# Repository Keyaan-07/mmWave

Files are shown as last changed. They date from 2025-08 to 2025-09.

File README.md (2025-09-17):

# mmWave Radar
This project includes building a complete mmWave radar that could operate at 60GHz. It uses the Texas Instruments IWRL6432 as the radar IC. This radar IC is operable between 57GHz-64GHz. The main goal of this project is to make a small module to use this IC as a radar. 
The board is a 6 layer board(4 layer was possible but 6 layers was cheaper). The 6 layer board costs only $2. 

[KICANVAS](https://kicanvas.org?)

# Images
Schematic:  
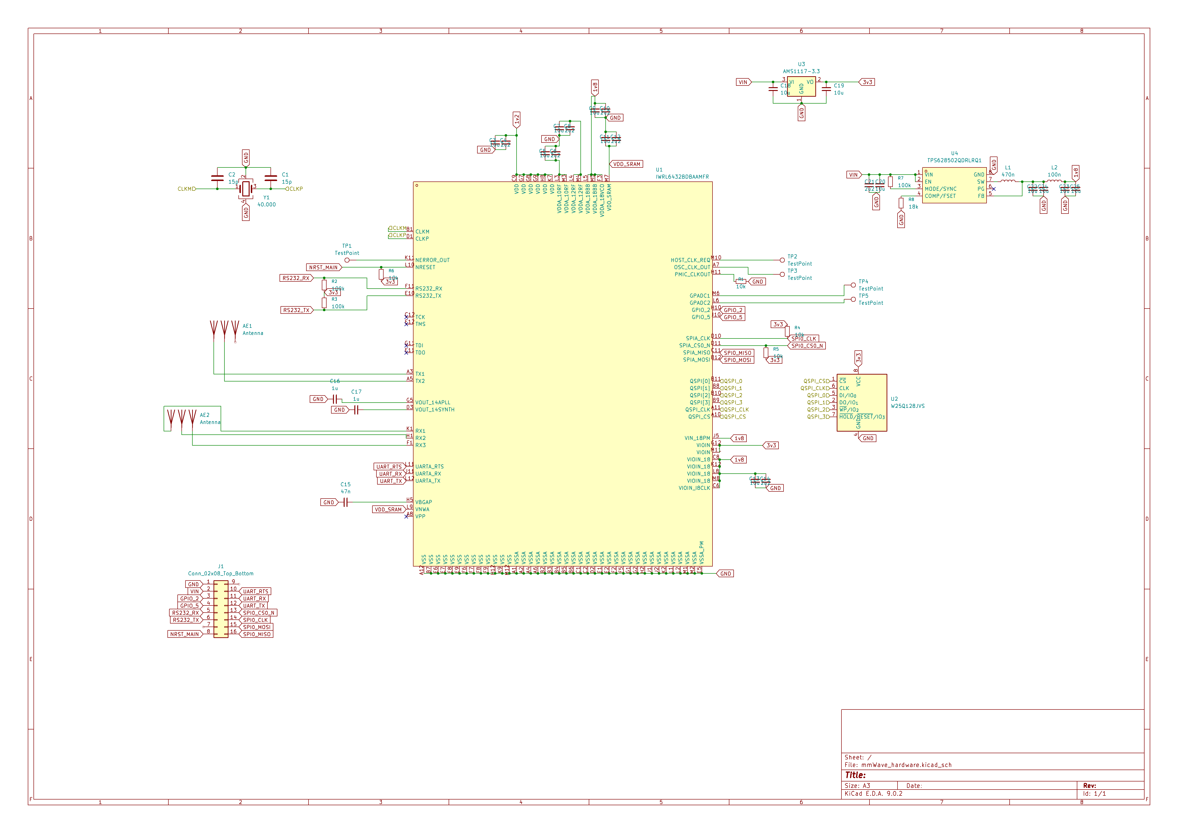
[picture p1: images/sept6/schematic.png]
schematic
  
PCB:  
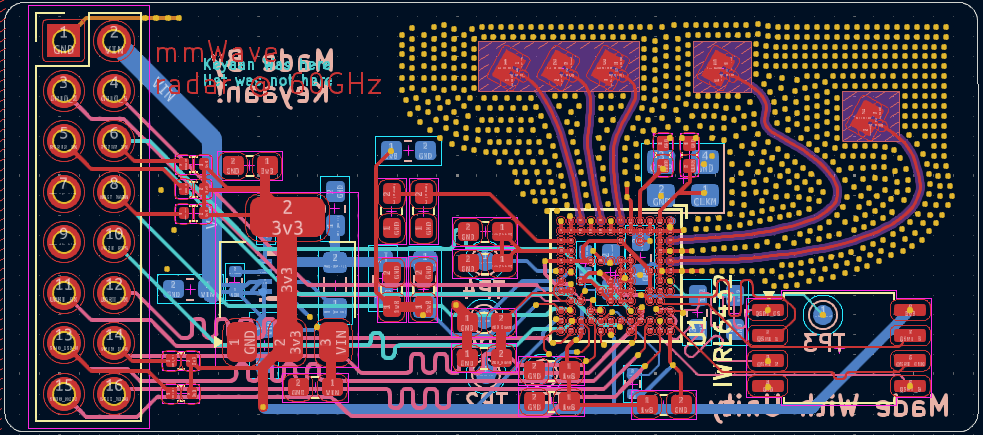
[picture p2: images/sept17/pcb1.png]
PCB1

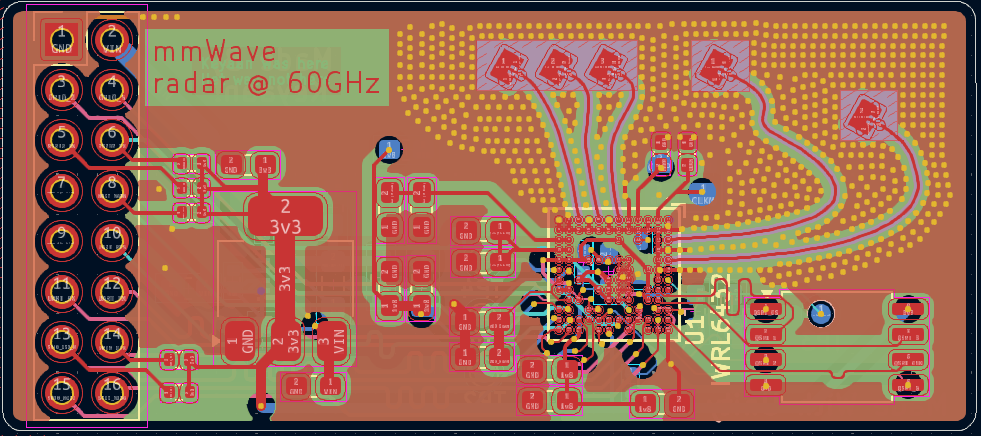
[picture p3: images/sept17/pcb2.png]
PCB2

3d: 
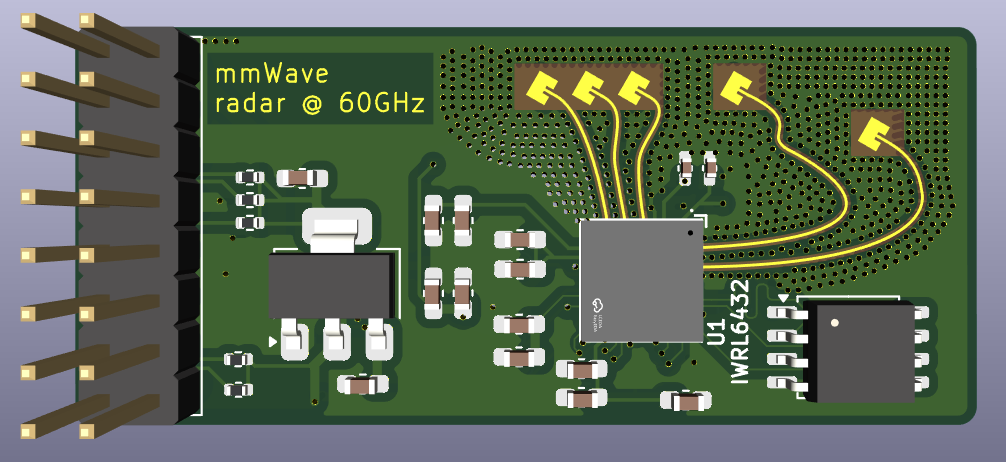
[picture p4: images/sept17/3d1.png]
3d1

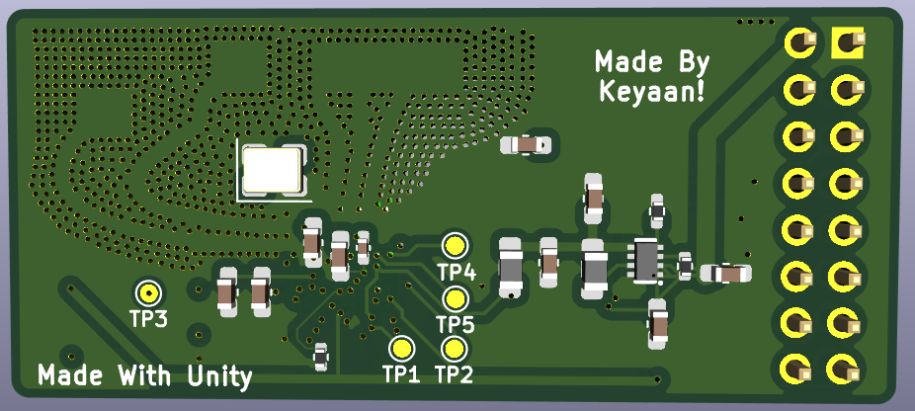
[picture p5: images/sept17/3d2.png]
3d2


# BOM
because the top sides contains BGA footprint which i've never soldered before, i am doing PCBA services for the top side and i will assemble the bottom side by myself
| ITEM | COST  | NOTE |
| --- | ----- | --- |
| PCB | 2 | 6-Layer PCB |
| PCBA | 51.71 | PCBA service from jlcpcb.com |
| SHIPPING from JLC | 9.28  | shipping cost |
| PCBA discount | -15 | 15 USD coupon from JLCONE yayy(valid till 19 sept) |
| LCSC Total (BOM_PCB_Bottom) | 14.55 | bottom side all parts |
| Total | 62.54 | USD |

----
### BOM - Top Side of PCB(PCBA recommened)
| Designator | Designation | Footprint | Price | Quantity(for 2 PCBA) | Amount(USD) | JLCPCB Part Number |
| --- | --- | --- | --- | --- | --- | --- |
| C1, C2 | 15p | 402 | 0.001 | 4 | 0.004 | C1548 |
| C6, C8, C10, C12, C14 | 2u2 | 603 | 0.006 | 10 | 0.06 | C23630 |
| C5, C11, C13, C18, C19, C25, C7, C9 | 10u | 603 | 0.056 | 16 | 0.896 | C19702 |
| R2, R3 | 100k | 402 | 0.001 | 2 | 0.002 | C25741 |
| R4, R5, R6 | 10k | 402 | 0.001 | 3 | 0.003 | C25744 |
| U1 | IWRL6432BDBAAMFR | BGA-102_L6.5-W6.5-P0.50-TL_TI_IWRL6432 | 16.0095 | 2 | 32.019 | C22428198 |
| U2 | W25Q128JVS | SOIC-8_5.3x5.3mm_P1.27mm | 1.131 | 2 | 2.262 | C97521 |
| U3 | AMS1117-3.3 | SOT-223-3_TabPin2 | 0.1615  | 2 | 0.323 | C6186 |
| | | | | Total | 35.569 | |
| PCB Cost | 2 | USD | | | | |
| Economic PCBA price | 51.71 | USD | | | | |
| Total | 53.71 | USD | | | | |

----
### BOM - bottom side of PCB(order and solder yourself)
if DNO is yes, i am not ordering the respective parts and cost has not been added to BOM.
| Designator | Designation | Footprint | DNO - Do not order | MOQ | Price  | Quantity | Amount(USD) | Supplier link |
| --- | --- | --- | --- | --- | --- | --- | --- | --- |
| C3, C20, C22, C23, C24 | 10u | 603 | No | Yes | 0.0197 | 20 | 0.394 | https://www.lcsc.com/product-detail/C7393892.html  |
| C4, C21 | 2u2 | 603 | No | Yes | 0.0228 | 20 | 0.456 | https://www.lcsc.com/product-detail/C48579298.html |
| C15 | 47n | 402 | Yes | \-  | 0 | 1 | 0 | https://www.lcsc.com/product-detail/C5142571.html  |
| C16, C17 | 1u | 603 | No | Yes | 0.0056 | 50 | 0.28 | https://www.lcsc.com/product-detail/C29936.html |
| L1 | 470n | 805 | No | Yes | 0.098  | 5 | 0.49 | https://www.lcsc.com/product-detail/C45385171.html |
| L2 | 100n | 805 | No | Yes | 0.098  | 5 | 0.49 | https://www.lcsc.com/product-detail/C45385168.html |
| R1 | 10k | 402 | Yes | \-  | 0 | 1 | 0 | https://www.lcsc.com/product-detail/C3020235.html  |
| R7 | 100k | 402 | No | Yes | 0.0277 | 20 | 0.554 | https://www.lcsc.com/product-detail/C313329.html |
| R8 | 18k | 402 | No | Yes | 0.005  | 10 | 0.05 | https://www.lcsc.com/product-detail/C2759512.html  |
| U4 | TPS628502QDRLRQ1 | SOT-583-8_L2.1-W1.2-P0.50-LS1.6-BR | No | No  | 1.94 | 3 | 5.82 | https://www.lcsc.com/product-detail/C3193229.html  |
| Y1 | 40MHz Crystal | Crystal_SMD_3225-4Pin_3.2x2.5mm | No | Yes | 5 | 0.1679 | 0.8395 | https://www.lcsc.com/product-detail/C18221410.html |
| J1 | Connector_02x08 | connector_pin2.54mm | No | Yes | 5 | 0.0586 | 0.293 | https://www.lcsc.com/product-detail/C42431811.html |
| | | | | | | | | |
| | Merchandise total: | 7.88 | USD | | | | | |
| | Shipping | 3.77 | USD | | | | | |
| | Handling charges | 3 | USD | | | | | |
| | Discount | \-0.1 | USD | | | | | |
| | Total | 14.55 | USD | | | | | |

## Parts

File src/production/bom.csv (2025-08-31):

Designator | Footprint | Quantity | Value | LCSC Part #
AE1 | TX_60GHz_microstrip_inset_patch | 1 | Antenna
AE2 | RX_60GHz_microstrip_inset_patch | 1 | Antenna
C1, C2 | 0402 | 2 | 15p
C10, C12, C14, C21, C4, C6, C8 | 0603 | 7 | 2u2
C11, C13, C18, C19, C20, C22, C23, C24, C25, C3, C5, C7, C9 | 0603 | 13 | 10u
C15 | 0402 | 1 | 47n
C16, C17 | 0603 | 2 | 1u
J1 | PinHeader_2x08_P2.54mm_Vertical | 1 | Conn_02x08_Top_Bottom
L1 | 0805 | 1 | 470n
L2 | 0805 | 1 | 100n
R1, R4, R5, R6 | 0402 | 4 | 10k
R2, R3, R7 | 0402 | 3 | 100k
R8 | 0402 | 1 | 18k
TP1, TP2, TP3, TP4, TP5 | TestPoint_Pad_D1.0mm | 5 | TestPoint
U1 | BGA-102_L6.5-W6.5-P0.50-TL_TI_IWRL6432BDQGAMFR | 1 | IWRL6432BDBAAMFR | C22428198
U2 | SOIC-8_5.3x5.3mm_P1.27mm | 1 | W25Q128JVS
U3 | SOT-223-3_TabPin2 | 1 | AMS1117-3.3
U4 | SOT-583-8_L2.1-W1.2-P0.50-LS1.6-BR | 1 | TPS628502QDRLRQ1 | C3193229
Y1 | Crystal_SMD_3225-4Pin_3.2x2.5mm | 1 | 40.000

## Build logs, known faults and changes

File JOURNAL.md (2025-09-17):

---
Title: "mmWave radar"
Author: "Keyaan"
Description: "mmWave radar module operating at 60GHz"
Created On: "10/8/2025"
---

## Total Time Spent: 14.5 hours

# August 10 2025

Starting with the journaling of this project!

found an amazing guide for the IC(IWRL6432), here it us https://www.ti.com/tool/TIDEP-01033#design-products

It is amazing and i started with the schematic too, i have plans that i will order BGA from LCSC and assemble myself home, but let's see what happens. 

# august 20 2025

i am in school today and will start with the schematic  

did most of the schematic work today itself, and now i will do final changes and then start with PCB..  

it is gonna be great  
oh wait, here is an image:  
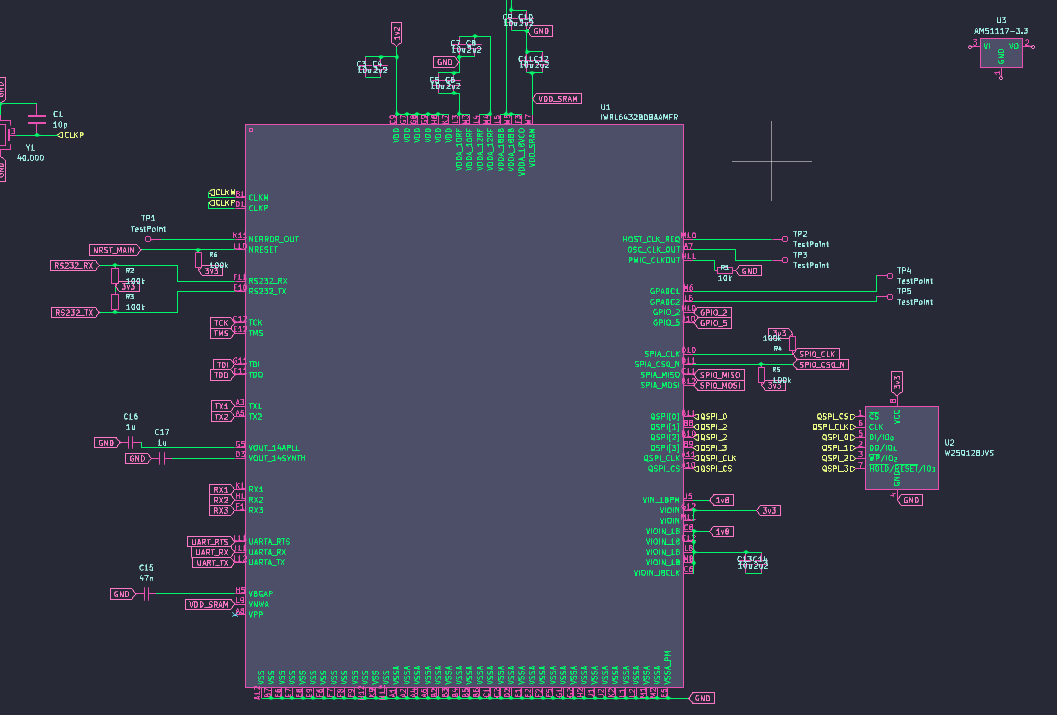
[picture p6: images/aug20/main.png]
main sch


oh wait, i just forgot that i would have to make the 1.8v voltage regulator :pf:

# August 22 2025

Gonna do a lot of work today, i will try to finish the 1.8v circuit, and start with the layout, i will route RF at the last because it is the hardest

umm i did some work today, it was idk what, mostly assigning stuff and trying to see what option would fit the best for me for reducing costs.

i have two options for making the PCB, 
- Either i can go for a single sided baord(not ideal for BGA
- I can do dual sided board(not ideal for costs as setup fee is 18 USD alone)

but a dual sided board is almost necessary as the components are BGA, and i would need decoupling caps all around it. 

so now basically i have to get 2 sided board made by myself, because i will only get JLCPCBA for 1 side, so i have kept all the back sided components(almost all are 0603) to handsolder pad size(that will be okay for me as i have handsoldered 0402😎). but i will still need to take care. 

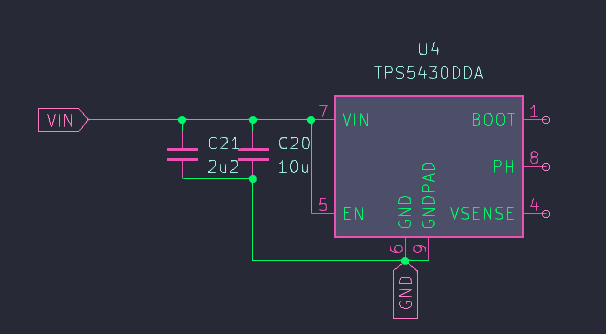
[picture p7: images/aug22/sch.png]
sch
  
only added this much of the circuit cuz i was finding the proper IC which is basic component in PCBA, and i was trying to understand it's circuit but i didn't understand it properly, will try tomorrow.  

This much PCB work is done:
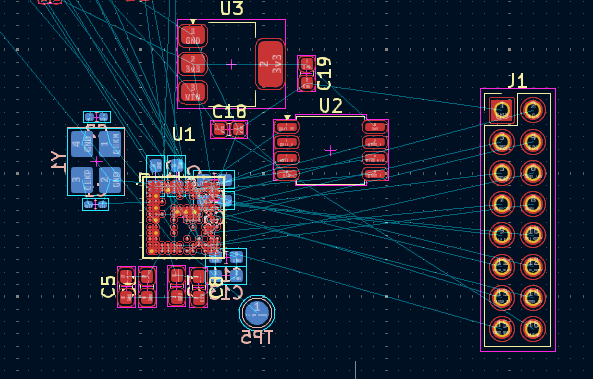
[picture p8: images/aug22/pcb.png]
pcb
  

i will try to complete schematic and placement by tomorrow...

### Time Spent today: about 1 hour

# august 23 2025
I am currently in school. gotta start working on the buck convertor, the 1.8v regulator

nvm, i am just changing the buck convertor to the tps62850 instead of the tps5430, because it has very low ripple output and it is recommeneded.

i changed my oscillator to [this](https://www.lcsc.com/product-detail/C5261245.html), and it required 10 pF locad cap so i will use the 15pFx2 capacitors, i already have them at my home.

### Time Spent today: about 25 mins

# august 24 2025

today, i am feeling very very happy as i figured out how i would mae the PCB for cheap as a 6 layer board and still have PCBA. i feel great thinking about it!

might route today..

didn't do any significant work today, just completed the 1.8v buck reg, and i still feel happy. will update with the photos tomorrow cuz too tired.  
Images:  
Buck Convertor:  
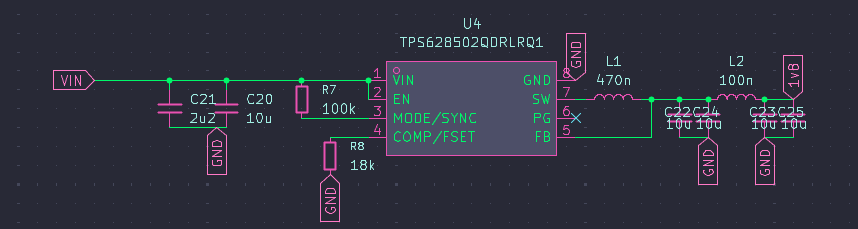
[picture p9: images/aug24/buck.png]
buck convertor
  
efficient way and make PCBs cheaper:  
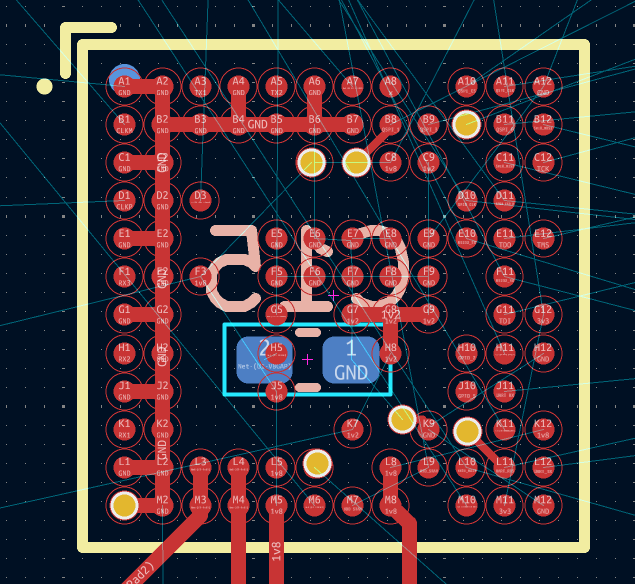
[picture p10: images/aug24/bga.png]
BGA pads
  

### time spent today: 30 mins

# august 25 2025
i am in school today, uploaded the photos for yesterday, now i will find 2 inductors and assign footprints and finally start with final routing

started with the PCB layout, will update soon

just completed with the layout, almost, probably, antennas remaining ofcourse  

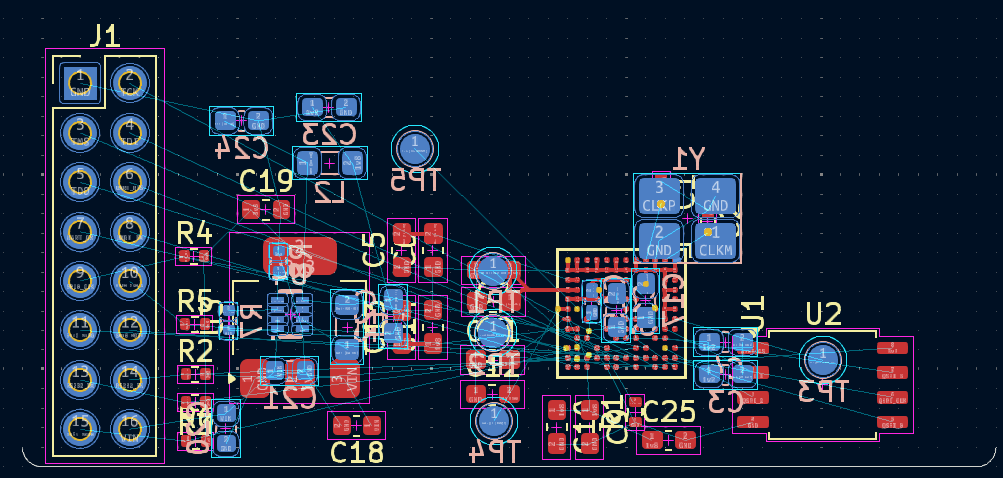
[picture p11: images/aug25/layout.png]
layout
  

did this, done that, now time for the harder part, RF.

well i have no experience making microstrip patch antennas and their feedlines but why not try making them. i'll be starting now

i am done, i think my patch antenna is ready

so basically, there are two popular types of feed lines in a patch, inset feedline and quarter-wave transformer feedline.  

Inset Feedline:  
inset feedline  
Quarter-wave Transformer feedline:  
q-wave transformer

and um after mind-storming, i figured out that i would use inset feedline(it is simpler to make lol). and I made it too!  

Here is something i made:  
my patch yayyy


it operates at 60GHz so the dimensions are pretty small. L=1.15mm and W=1.51mm

i felt so happy when it turned out great

### time spent today: 2 hours 30 mins

# August 26 2025

I am in school, made the RX antenna part completely, the array consists of 3 antennas at lambda/2 length

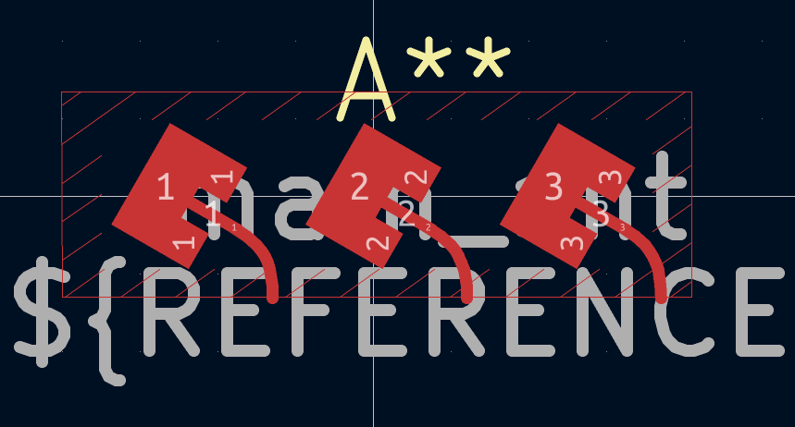
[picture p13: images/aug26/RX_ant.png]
RX array


now, i have to make a custom ANT symbol.  
did just make it in 5 mins  

finally, i think all the antennas are ready, with all the final touches done too, and i removed the wires coming out of the antennas, because they were causing problems. here is the current look:  
### RX:  
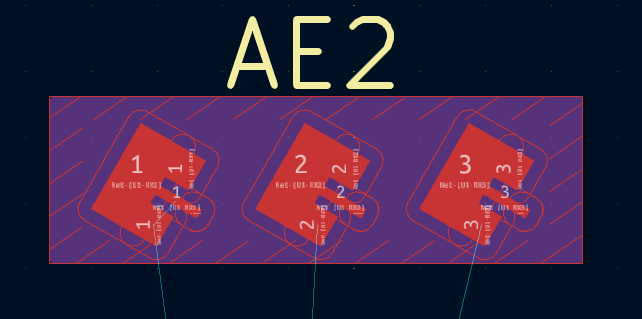
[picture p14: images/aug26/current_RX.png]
current RX antenna
  
### TX:  
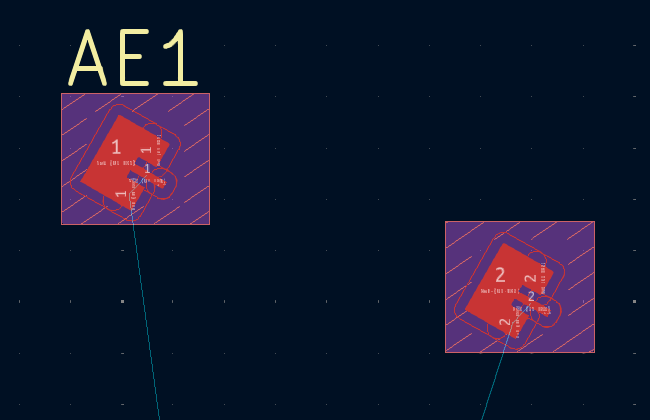
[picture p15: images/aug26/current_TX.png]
current TX antenna


well well well, my layout is done, feel super good!  
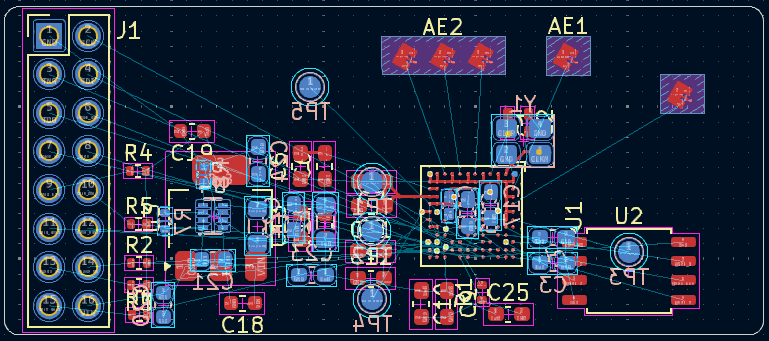
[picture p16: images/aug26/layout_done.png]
layout done


### time spent today: 1 hour 10 mins

# August 28

Started with PCB layout in school.

I have made a decision to remove the JTAG pins, i think that those are unnecessary, because i am confident that i build great circuits, and thus there is no need for debugging(BPS Space reference). 

oh my god, my PCB is almost complete, just two Antenna connections remaining!

i guess the PCB is done, some final touches remaining:  
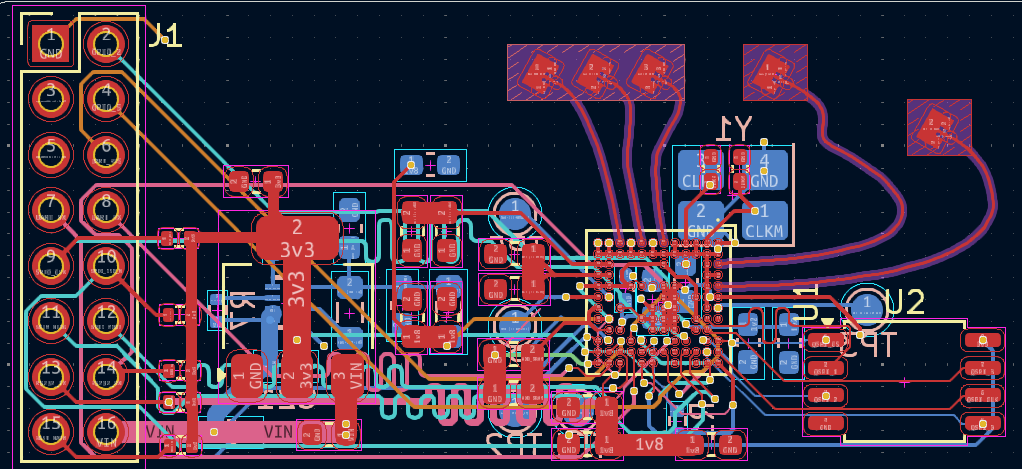
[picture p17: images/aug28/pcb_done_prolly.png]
pcb doneee

(i am at 64 vias rn let's see how many i add)
### Time Spent Today: 4 hours

# August 29 2025
today, idk how but i forgot to journal, and i have added so many damn vias, i am a crazy crazy person, they were like 64 yesterday, now they are like 200 something, all ground vias, atp i am just making jlc suffer, and i spent an hour trying my best to squeeze as many vias as i can :skull:

### Time spent today: 1 hour

# August 30 2025

i am done. THE PCB IS FINALLY READY  

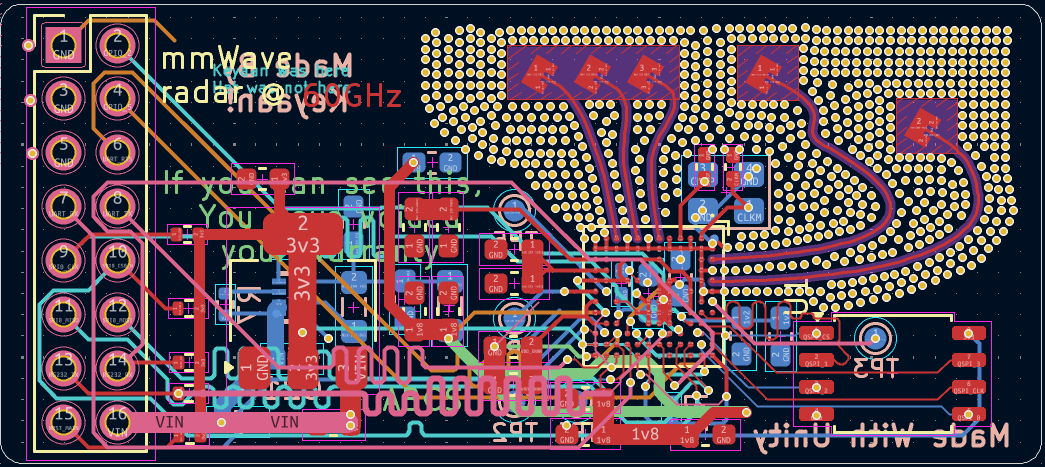
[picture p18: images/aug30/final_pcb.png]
final PCB
  
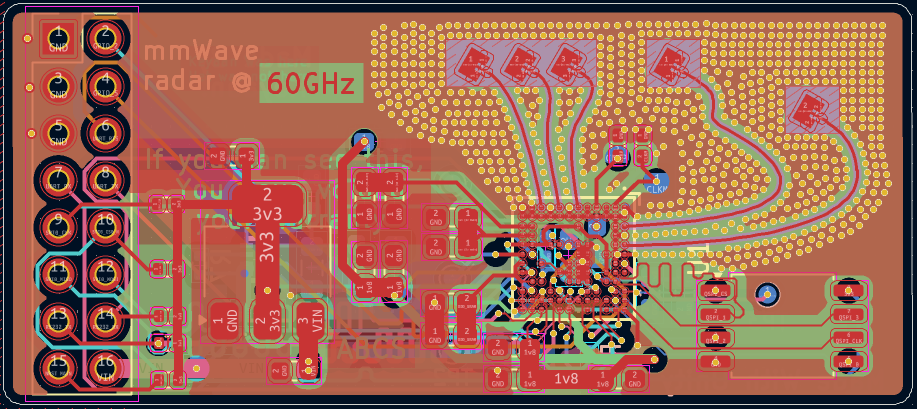
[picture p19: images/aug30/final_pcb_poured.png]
final PCB
  
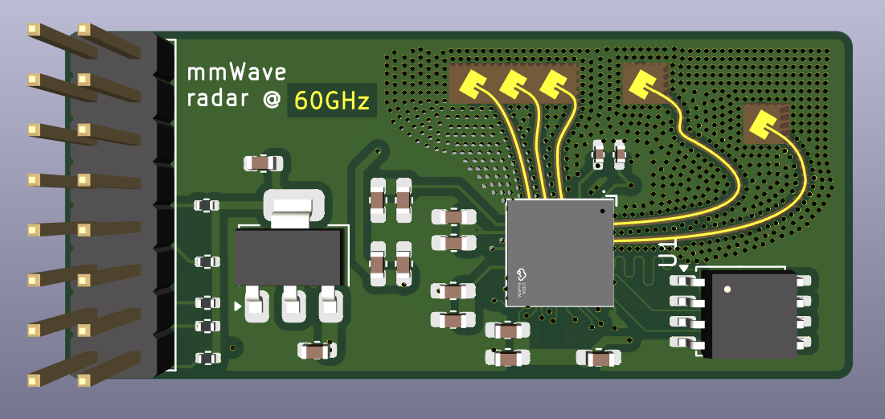
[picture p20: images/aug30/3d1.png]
3d render image 1

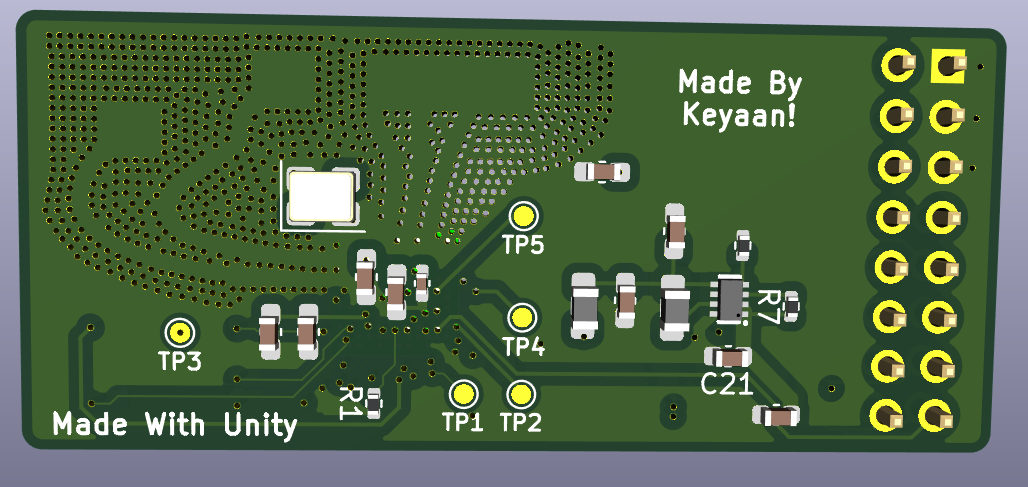
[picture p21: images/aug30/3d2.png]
3d render image 2

### time spent today: 20 mins  

# August 31 2025
grounded ends today, and i have to submit this proj, so i am gonna do that today itself!

# sept 6 2025
Grounded ends 20 sept!! i have started routing again, will update later on!! Worked on it, and i think i am done with the board again.

for proper routing, i changed the pin config many many times, and thus i have arrived to what i have today, ladies and gentlemen.  

Schematic:  
schematic  
PCB:  
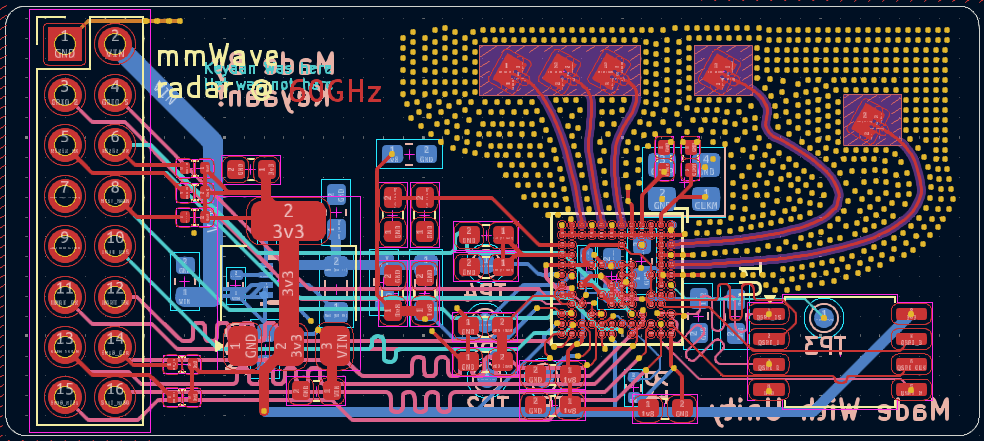
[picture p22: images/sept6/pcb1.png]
  
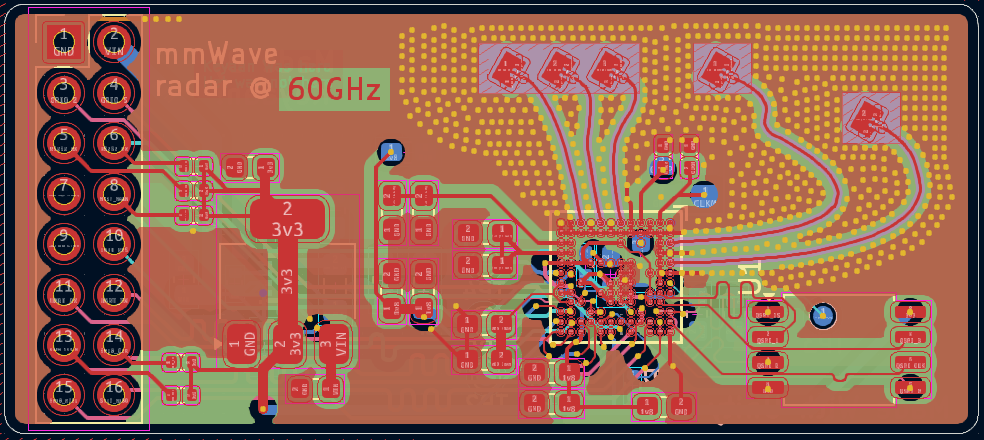
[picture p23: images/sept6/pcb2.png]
  
3d:  
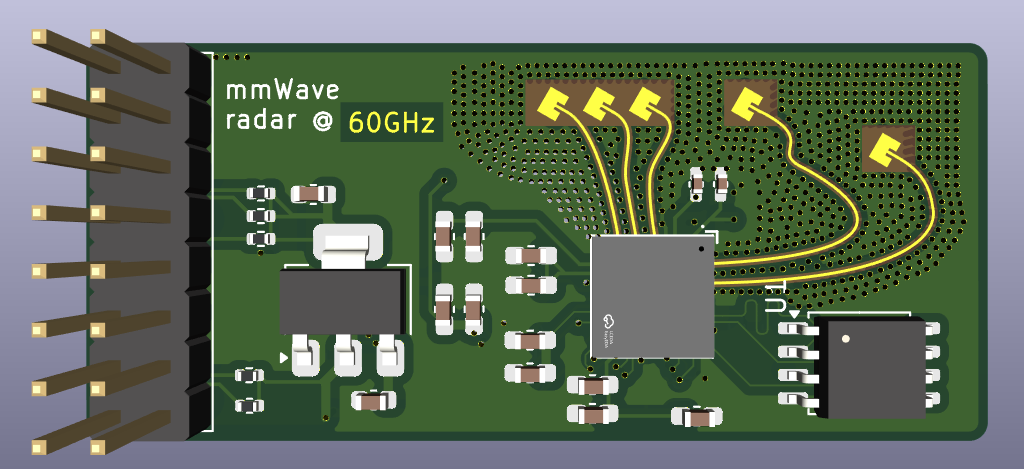
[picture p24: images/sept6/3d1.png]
  
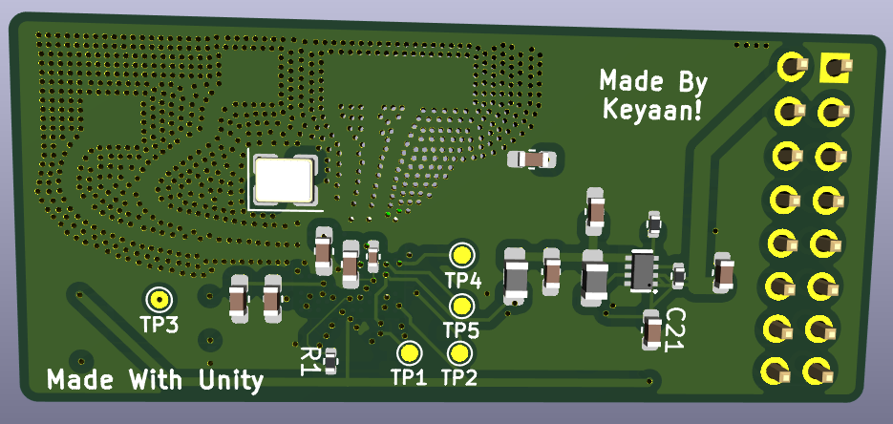
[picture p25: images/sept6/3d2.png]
  
I wrote a bit of the readme too!
### Time spent today: 2.5 hours

# sept 10 2025
i have sat on 13th, so i'm working less these days, anyways, i'll update production files today

oh shoot, i discovered a problem with the footprint assignment too, gotta fix that rn.

did a bit of changes to the silkscreen too, will need to change the images again :noo:

### time spent today: 20 mins

# sept 11 2025
I updated the images today, will probably submit by night of 13 sept or 14 sept morning. NICE!

final images:  
Schematic:  
schematic  
PCB:  
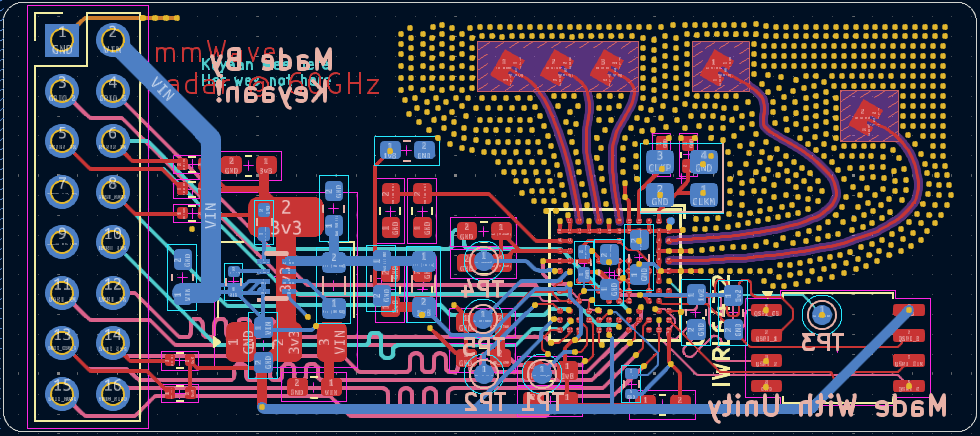
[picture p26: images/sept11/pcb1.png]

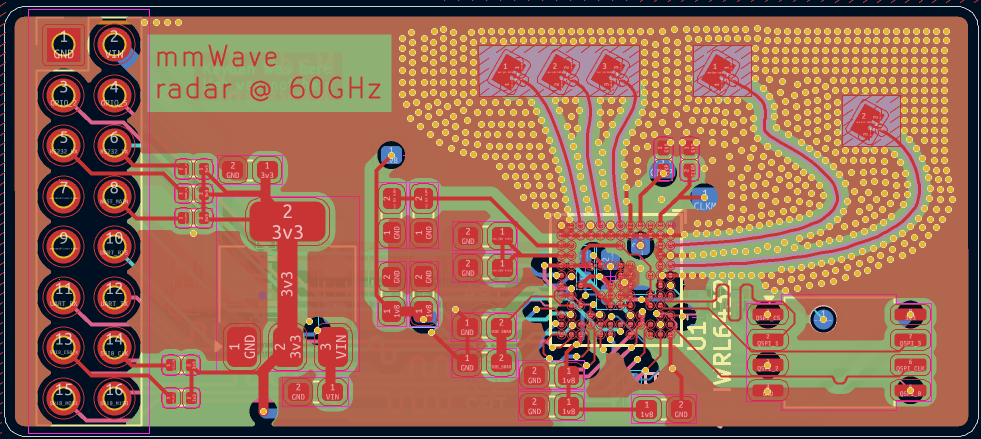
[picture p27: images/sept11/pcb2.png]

3d: 
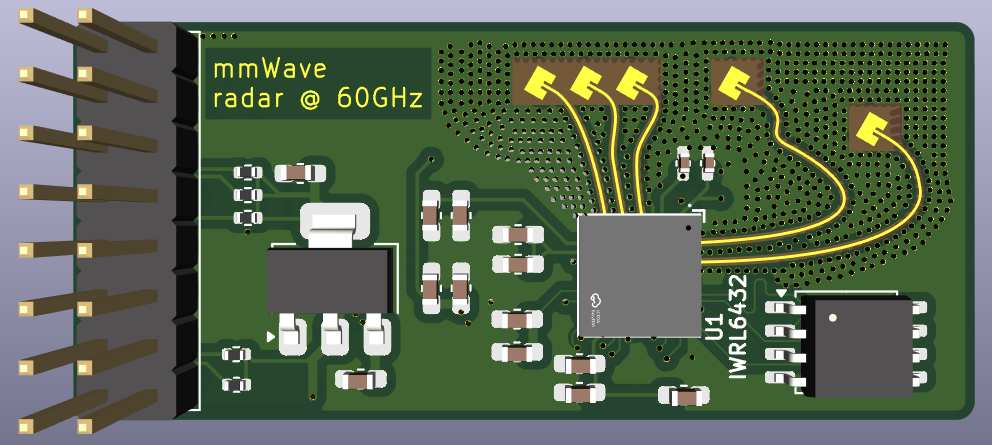
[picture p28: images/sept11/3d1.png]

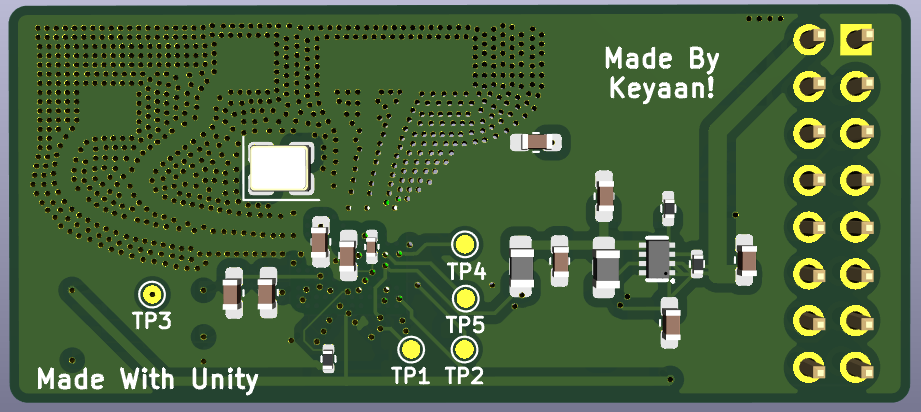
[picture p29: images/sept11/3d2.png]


# sept 17 2025
SAT is done! gotta start with the radar today, so i made a minor changes to it and now i have to again change all the images. lol.

everything is now done, i am gonna submit today itself.

hell yeah! everything is done, gonna submit now..

### time spent today: 1 hour 45 mins

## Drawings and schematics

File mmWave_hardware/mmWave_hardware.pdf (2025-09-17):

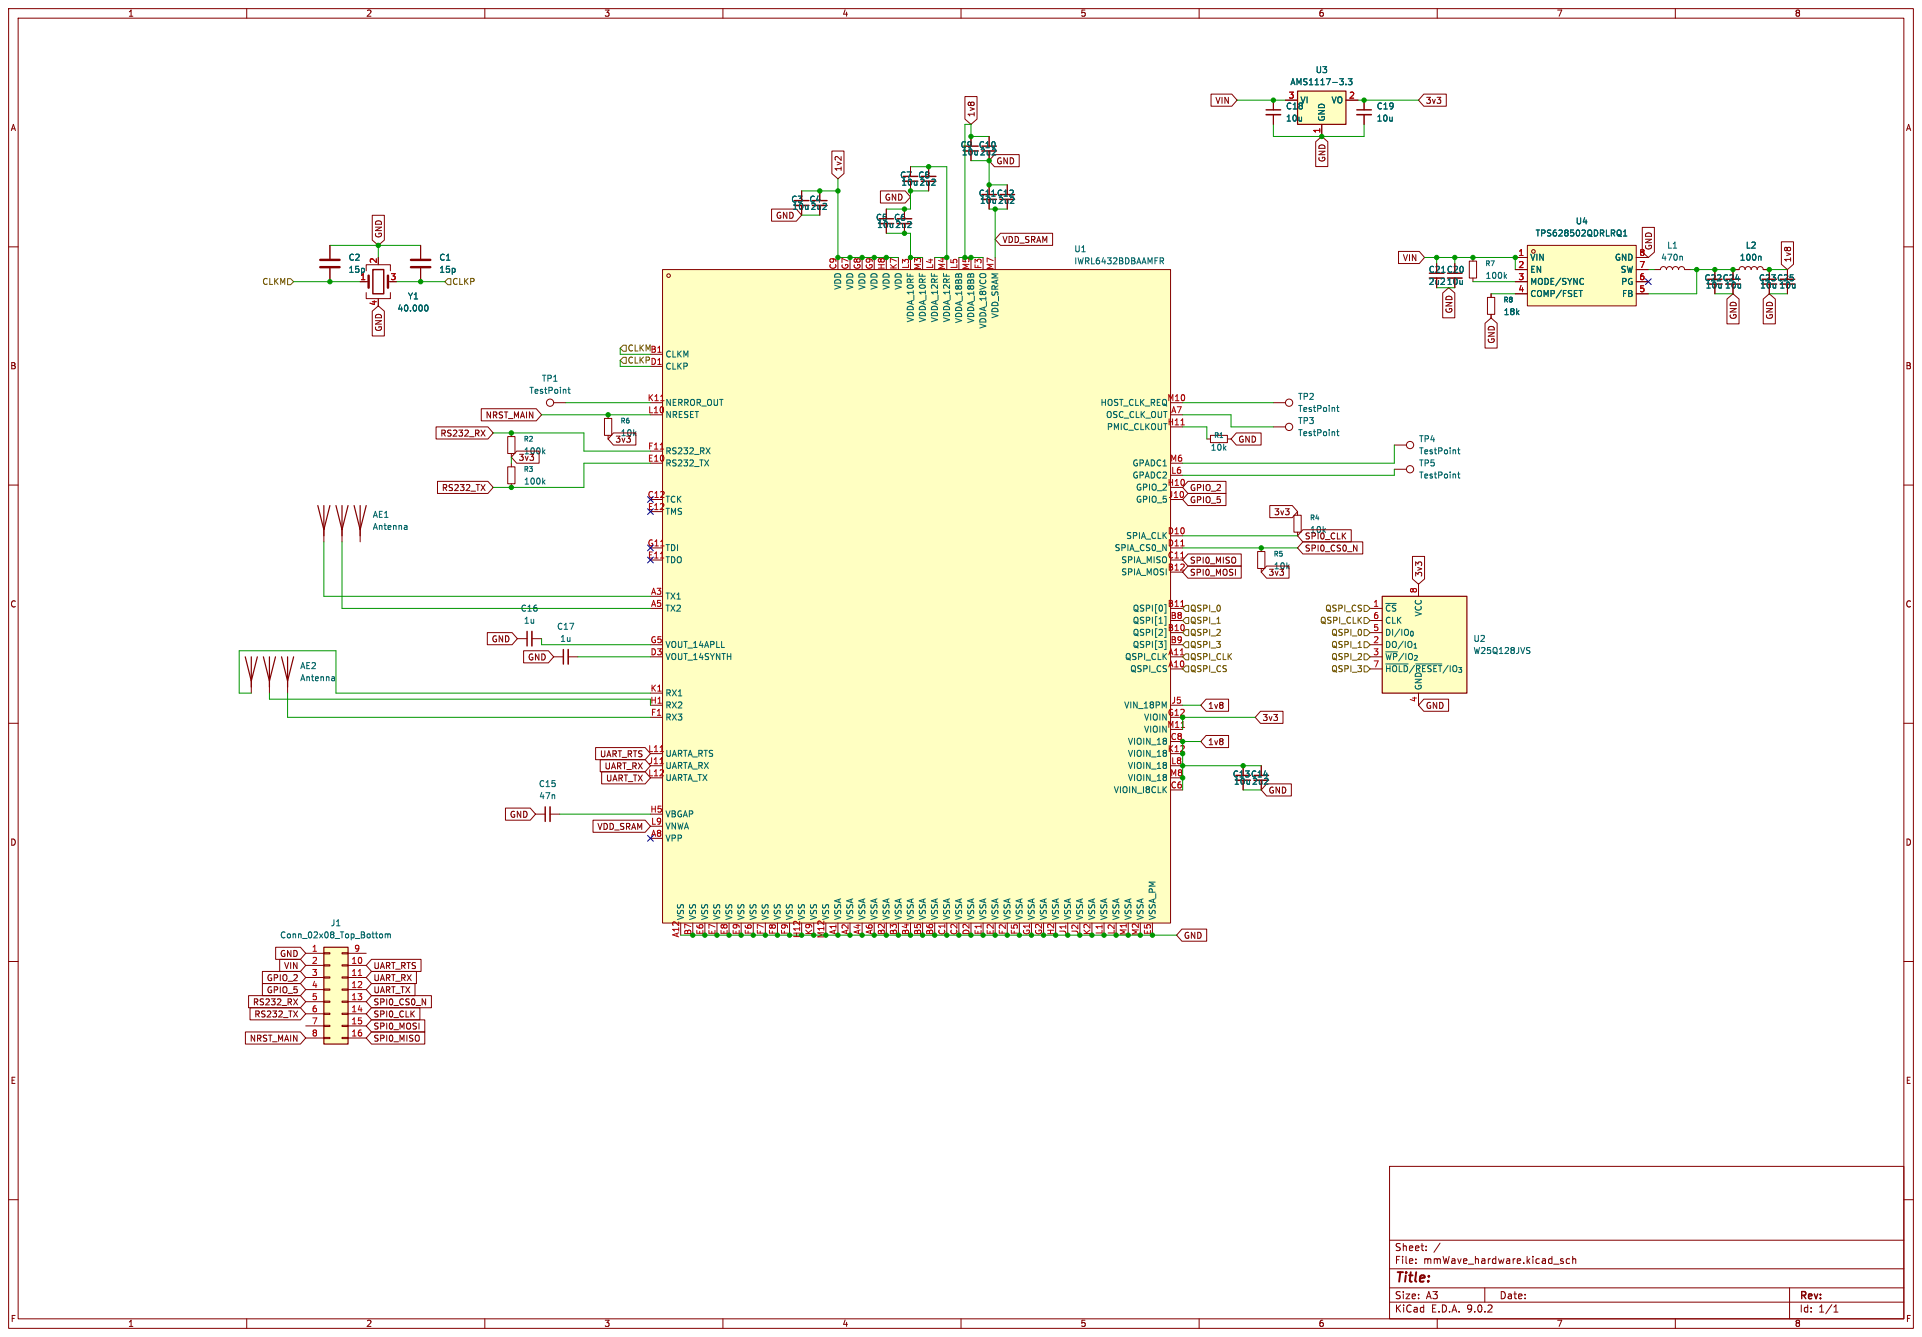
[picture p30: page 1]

Id: 1/1 Title: File: mmWave_hardware.kicad_sch Sheet: /

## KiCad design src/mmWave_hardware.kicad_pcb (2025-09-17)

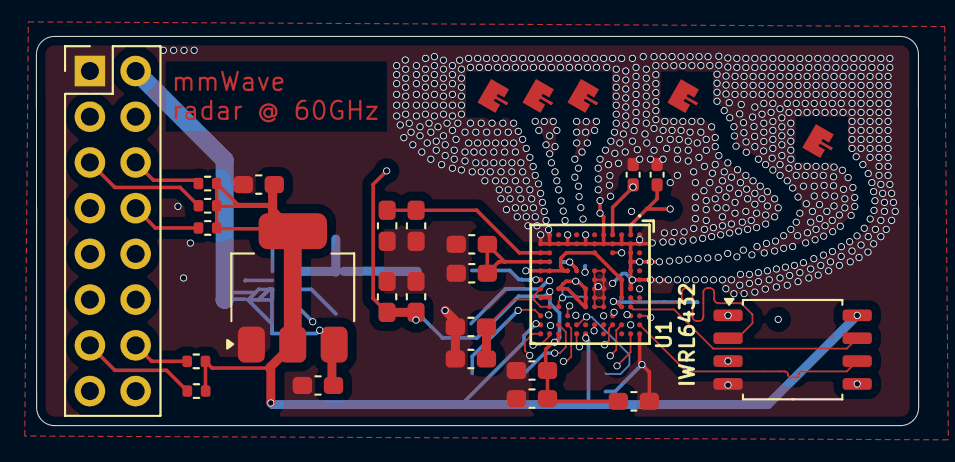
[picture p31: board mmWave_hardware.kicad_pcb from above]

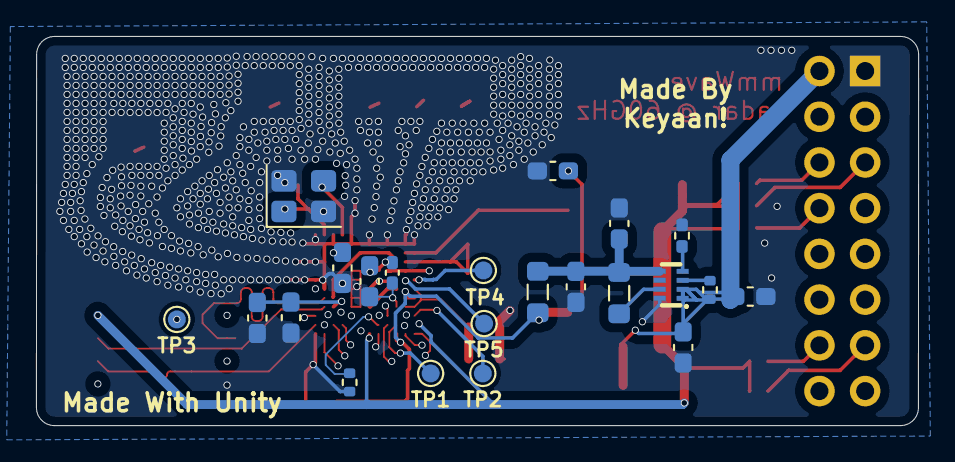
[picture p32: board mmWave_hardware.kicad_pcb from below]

Board: 6 copper layers, 49.0 x 21.6 mm, 48 parts (22 on the bottom side), 46 nets.

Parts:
AE1: Antenna; TX_60GHz_microstrip_inset_patch
AE2: Antenna; RX_60GHz_microstrip_inset_patch
C1, C2: 15p; C_0402_1005Metric_Pad0.74x0.62mm_HandSolder
C3, C5, C7, C9, C11, C13, C18, C19, C20, C22, C23, C24, C25: 10u; C_0603_1608Metric_Pad1.08x0.95mm_HandSolder
C4, C6, C8, C10, C12, C14, C21: 2u2; C_0603_1608Metric_Pad1.08x0.95mm_HandSolder
C15: 47n; C_0402_1005Metric_Pad0.74x0.62mm_HandSolder
C16, C17: 1u; C_0603_1608Metric_Pad1.08x0.95mm_HandSolder
J1: Conn_02x08_Top_Bottom; PinHeader_2x08_P2.54mm_Vertical
L1: 470n; L_0805_2012Metric_Pad1.05x1.20mm_HandSolder
L2: 100n; L_0805_2012Metric_Pad1.05x1.20mm_HandSolder
R1, R4, R5, R6: 10k; R_0402_1005Metric
R2, R3, R7: 100k; R_0402_1005Metric
R8: 18k; R_0402_1005Metric_Pad0.72x0.64mm_HandSolder
TP1, TP2, TP3, TP4, TP5: TestPoint; TestPoint_Pad_D1.0mm
U1: IWRL6432BDBAAMFR; BGA-102_L6.5-W6.5-P0.50-TL_TI_IWRL6432BDQGAMFR
U2: W25Q128JVS; SOIC-8_5.3x5.3mm_P1.27mm
U3: AMS1117-3.3; SOT-223-3_TabPin2
U4: TPS628502QDRLRQ1; SOT-583-8_L2.1-W1.2-P0.50-LS1.6-BR
Y1: 40.000; Crystal_SMD_3225-4Pin_3.2x2.5mm

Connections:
1v2: C3.1, C4.1, U1.C9 (VDD), U1.G7 (VDD), U1.G8 (VDD), U1.G9 (VDD), U1.H8 (VDD), U1.K7 (VDD)
1v8: C9.1, C10.1, C13.1, C14.1, C23.1, C25.1, L2.2, U1.C6 (VIOIN_I8CLK), U1.C8 (VIOIN_18), U1.F3 (VDDA_18VCO), U1.J5 (VIN_18PM), U1.K12 (VIOIN_18), U1.L5 (VDDA_18BB), U1.L8 (VIOIN_18), U1.M5 (VDDA_18BB), U1.M8 (VIOIN_18)
3v3: C19.1, R2.2, R3.1, R4.2, R5.2, R6.2, U1.G12 (VIOIN), U1.M11 (VIOIN), U2.8 (VCC), U3.2 (VO)
/CLKM: C2.2, U1.B1 (CLKM), Y1.1
/CLKP: C1.2, U1.D1 (CLKP), Y1.3
/QSPI_0: U1.B11 (QSPI[0]), U2.5 (DI/IO_{0})
/QSPI_1: U1.B8 (QSPI[1]), U2.2 (DO/IO_{1})
/QSPI_2: U1.B10 (QSPI[2]), U2.3 (~WP/IO_{2})
/QSPI_3: U1.B9 (QSPI[3]), U2.7 (~HOLD/~RESET/IO_{3})
/QSPI_CLK: U1.A11 (QSPI_CLK), U2.6 (CLK)
/QSPI_CS: U1.A10 (QSPI_CS), U2.1 (~CS)
GND: C1.1, C2.1, C3.2, C4.2, C5.1, C6.1, C7.2, C8.2, C9.2, C10.2, C11.1, C12.1, C13.2, C14.2, C15.1, C16.1, C17.1, C18.2, C19.2, C20.2, C21.2, C22.2, C23.2, C24.2, C25.2, J1.1, R1.1, R8.2, U1.A1 (VSSA), U1.A2 (VSSA), U1.A4 (VSSA), U1.A6 (VSSA), U1.A12 (VSS), U1.B2 (VSSA), U1.B3 (VSSA), U1.B4 (VSSA), U1.B5 (VSSA), U1.B6 (VSSA), U1.B7 (VSS), U1.C1 (VSSA), U1.C2 (VSSA), U1.D2 (VSSA), U1.E1 (VSSA), U1.E2 (VSSA), U1.E5 (VSSA_PM), U1.E6 (VSS), U1.E7 (VSS), U1.E8 (VSS), U1.E9 (VSS), U1.F2 (VSSA), U1.F5 (VSSA), U1.F6 (VSS), U1.F7 (VSS), U1.F8 (VSS), U1.F9 (VSS), U1.G1 (VSSA), U1.G2 (VSSA), U1.H2 (VSSA), U1.H12 (VSS), U1.J1 (VSSA), U1.J2 (VSSA), U1.K2 (VSSA), U1.K9 (VSS), U1.L1 (VSSA), U1.L2 (VSSA), U1.M1 (VSSA), U1.M2 (VSSA), U1.M12 (VSS), U2.4 (GND), U3.1 (GND), U4.8 (GND), Y1.2, Y1.4
GPIO_2: J1.3, U1.H10 (GPIO_2)
GPIO_5: J1.4, U1.J10 (GPIO_5)
NRST_MAIN: J1.8, R6.1, U1.L10 (NRESET)
unnamed: C5.2, C6.2, U1.L3 (VDDA_10RF), U1.M3 (VDDA_10RF)
unnamed: C7.1, C8.1, U1.L4 (VDDA_12RF), U1.M4 (VDDA_12RF)
unnamed: TP4.1, U1.M6 (GPADC1)
unnamed: TP5.1, U1.L6 (GPADC2)
unnamed: TP2.1, U1.M10 (HOST_CLK_REQ)
unnamed: TP1.1, U1.K11 (NERROR_OUT)
unnamed: TP3.1, U1.A7 (OSC_CLK_OUT)
unnamed: R1.2, U1.H11 (PMIC_CLKOUT)
unnamed: AE2.1 (A), U1.K1 (RX1)
unnamed: AE2.2 (A), U1.H1 (RX2)
unnamed: AE2.3 (A), U1.F1 (RX3)
unnamed: AE1.1 (A), U1.A3 (TX1)
unnamed: AE1.2 (A), U1.A5 (TX2)
unnamed: C15.2, U1.H5 (VBGAP)
unnamed: C16.2, U1.G5 (VOUT_14APLL)
unnamed: C17.2, U1.D3 (VOUT_14SYNTH)
unnamed: R8.1, U4.4 (COMP/FSET)
unnamed: C22.1, C24.1, L1.2, L2.1, U4.5 (FB)
unnamed: R7.2, U4.3 (MODE/SYNC)
unnamed: L1.1, U4.7 (SW)
RS232_RX: J1.5, R2.1, U1.F11 (RS232_RX)
RS232_TX: J1.6, R3.2, U1.E10 (RS232_TX)
SPI0_CLK: J1.14, R4.1, U1.D10 (SPIA_CLK)
SPI0_CS0_N: J1.13, R5.1, U1.D11 (SPIA_CS0_N)
SPI0_MISO: J1.16, U1.C11 (SPIA_MISO)
SPI0_MOSI: J1.15, U1.B12 (SPIA_MOSI)
UART_RTS: J1.10, U1.L11 (UARTA_RTS)
UART_RX: J1.11, U1.J11 (UARTA_RX)
UART_TX: J1.12, U1.L12 (UARTA_TX)
VDD_SRAM: C11.2, C12.2, U1.L9 (VNWA), U1.M7 (VDD_SRAM)
VIN: C18.1, C20.1, C21.1, J1.2, R7.1, U3.3 (VI), U4.1 (VIN), U4.2 (EN)

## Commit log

2025-08-23 new buck conv
    [mmWave_hardware.kicad_pcb, mmWave_hardware.kicad_sch]
2025-08-26 antenna array
    [mmWave_hardware.kicad_pcb]
2025-08-26 Layout Complete
    [mmWave_hardware.kicad_pcb]
2025-08-28 added images of pcb
2025-08-28 PCB Complete
    [bom.csv, designators.csv, mmWave_hardware.kicad_pcb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]
2025-08-30 PCB Done
    [mmWave_hardware.kicad_pcb, mmWave_hardware.kicad_sch]
2025-08-30 images of final pcb
2025-08-31 pcb changes
    [bom.csv, mmWave_hardware.kicad_pcb, positions.csv]
2025-09-02 unrouting started
    [mmWave_hardware.kicad_pcb]
2025-09-04 unrouted all
    [mmWave_hardware.kicad_pcb]
2025-09-06 routing done
    [mmWave_hardware.kicad_pcb, mmWave_hardware.kicad_sch]
2025-09-06 Final PCB(Probably)
    [mmWave_hardware.kicad_pcb]
2025-09-10 updated production files
    [positions.csv]
2025-09-10 fixed footprint issue
    [mmWave_hardware.kicad_pcb, mmWave_hardware.kicad_sch]
2025-09-10 changed silkscreen
    [mmWave_hardware.kicad_pcb, mmWave_hardware.kicad_sch]
2025-09-11 added PCB images
2025-09-11 silkscreen changes
    [mmWave_hardware.kicad_pcb]
2025-09-17 added BOM
2025-09-17 Uploaded schematic
2025-09-17 src uploaded
    [bom.csv, designators.csv, mmWave_hardware.kicad_pcb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]
2025-09-17 BOM files
    [BOM_PCB_Bottom.xlsx, BOM_PCB_Top.xlsx]
2025-09-17 added gerber
